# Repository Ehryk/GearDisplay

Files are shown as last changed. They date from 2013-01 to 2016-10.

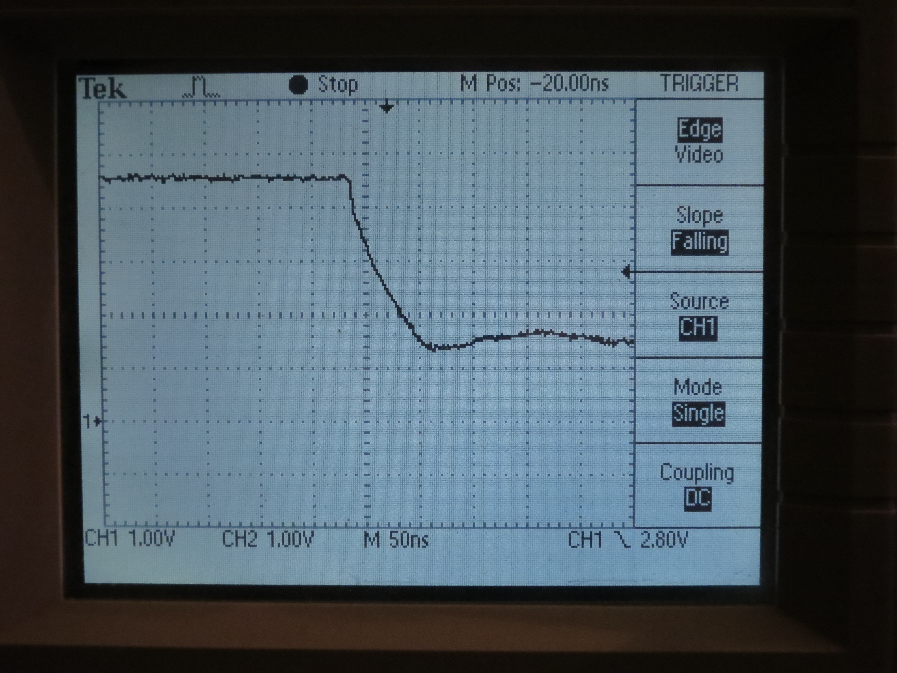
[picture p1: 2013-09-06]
Documentation/Pictures/2013.09.06 - Install/4 - Checking with Oscilloscope.jpg

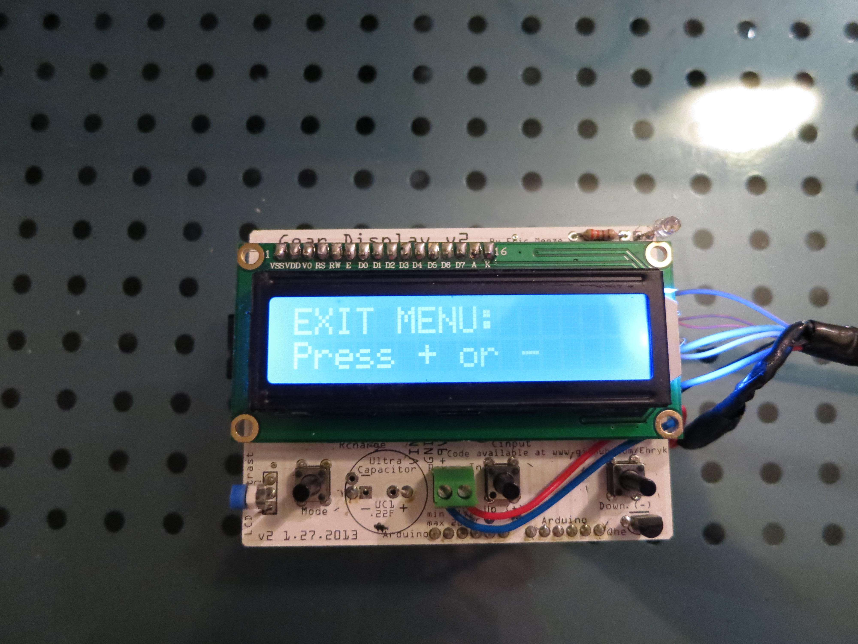
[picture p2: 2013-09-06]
Documentation/Pictures/2013.09.06 - Install/3 - Display On.jpg

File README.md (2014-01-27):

GearDisplay
===========

This is an Arduino based project that displays the currently selected gear in a manual transmission vehicle. It uses six Hall-Effect sensors connected to the analog inputs of the arduino, calculates the average, and then uses an adjustable tolerance value to see if any are outside of this tolerance value from the average. Ideally, if none are out of tolerance the transmission is in neutral, if only one is then it is the selected gear, and if more than one is then the tolerance is too low and it displays an Error. 

The key to this setup is one or more magnets on the shifter's metal shaft, and the six hall effect sensors at the approximate locations of the edge of the shaft when engaged in each gear (1-5 and Reverse). Six or more speeds are currently not supported, though less than five are (though the unused hall effect sensors should remain in the circuit providing roughly 2.5V).

**Videos**

 - Basic Operation Video: [Basic Operation Video](https://www.youtube.com/watch?v=FTQq74HFvWU)
 - Menu System in Detail: [Menu System Video](https://www.youtube.com/watch?v=9K3rxGJS8n4)
 - Sensor Voltages: [Sensor Voltages Video](https://www.youtube.com/watch?v=qHEV87LpvVI)

**Core**

This is a display-agnostic version of the core functionality. It will read the analog inputs, determine gear selection, and that's it. It will log detailed information to the Serial port if in debug mode and a device is listening for it. If you have your own display that isn't listed in the versions, start here.

**v1 - 16x2 LCD Display**

This is the first version I wrote, tuned for a standard 16x2 LCD screen. A schematic is included. This uses three push button switches and a potentiometer for the following functions: mode switching, tolerance up, tolerance down, and LCD contrast, respectively. This version has 12 display modes:

1. Basic Display
1. Basic Display - With Accent
1. Advanced Display
1. Advanced Display - With Accent
1. Variables Display (tolerance in voltage)
1. Variables Display (tolerance in internal units [0-1023])
1. Gear Voltages (Debug Only)
1. Gear Values (Debug Only)
1. Fill Mode - fills every position with the character of the gear (N for Neutral, 1 for first, etc.)
1. Enter Menu (press + or -)
1. Enter Log (press + or -)
1. Credits
1. Display off

v1

**v2 - 16x2 LCD Display - In Casing**

v1 was made to be mounted with the circuit board visible, but I then found some nice black project cases on eBay. This version is smaller to fit in the enclosure, uses an ultracapacitor keep-alive circuit to keep power to the unit briefly after the vehicle has been turned off for the final EEPROM writes, uses a transistor to selectively power the Hall Effect sensors (optional), and MC14490 hardware switch debouncer (optional). I installed it in a 2003 Jeep Wrangler Rubicon.

v2 Installed
v2 Sensor Ring

**v3 - Color Touchscreen**

Version 3 uses a color touchscreen for both display and user input, mode switching, and tolerance adjustments. Will come soon.

**Library**

This is where I will put a .cpp library of common features, when I get to it.

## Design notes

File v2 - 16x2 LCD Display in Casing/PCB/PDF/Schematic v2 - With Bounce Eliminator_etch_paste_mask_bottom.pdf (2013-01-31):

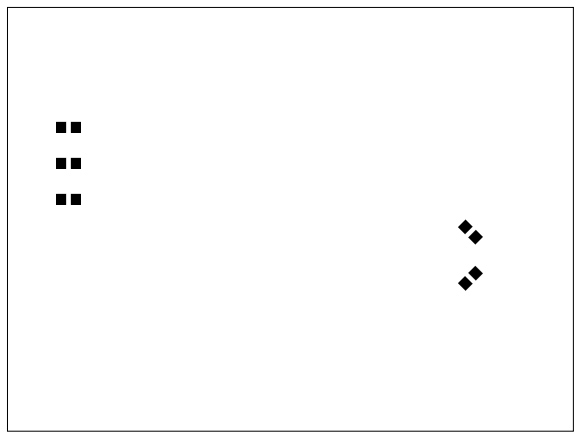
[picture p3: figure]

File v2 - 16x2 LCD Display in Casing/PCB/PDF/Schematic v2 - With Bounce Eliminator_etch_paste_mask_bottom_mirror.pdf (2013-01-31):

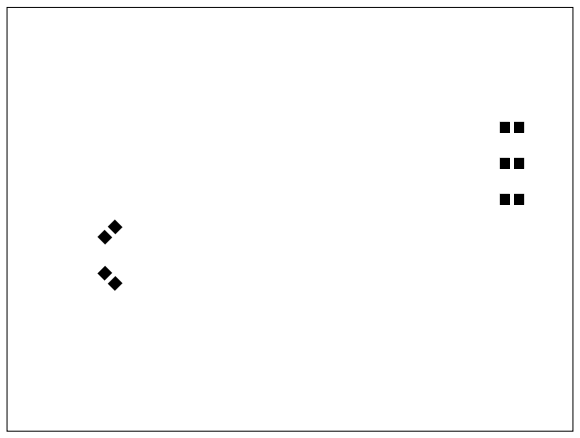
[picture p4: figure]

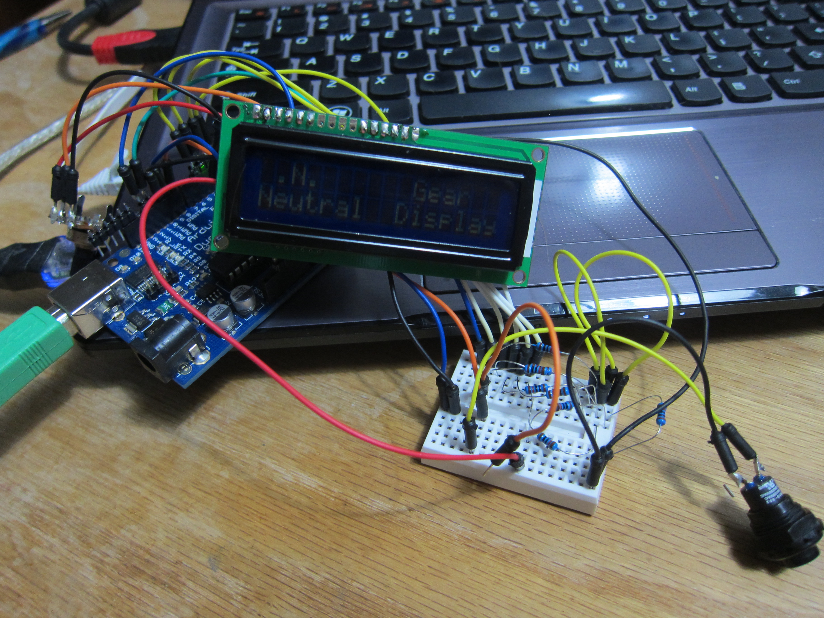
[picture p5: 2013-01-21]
Documentation/Pictures/2013.01.10 - Breadboard/4 - Neutral.jpg

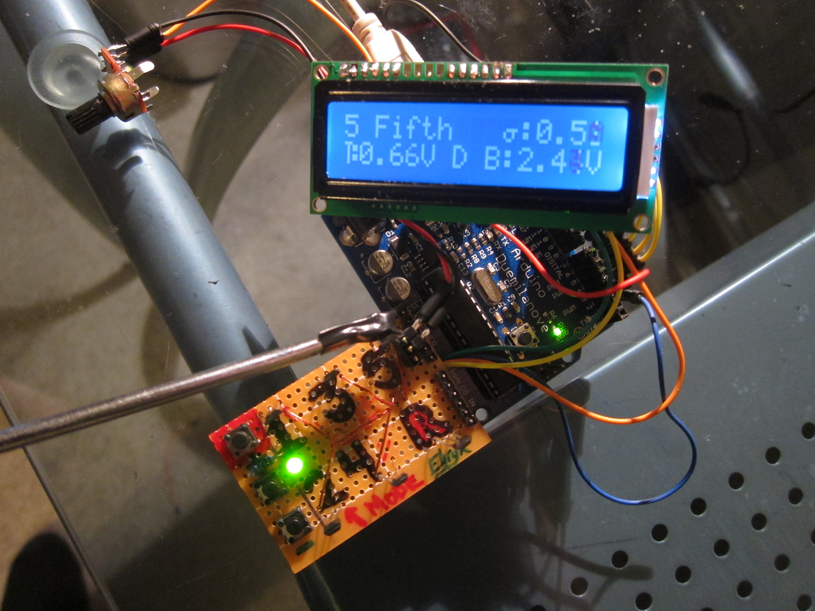
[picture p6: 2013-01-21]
Documentation/Pictures/2013.01.20 - Stripboard/2 - Advanced Display - In Gear.jpg

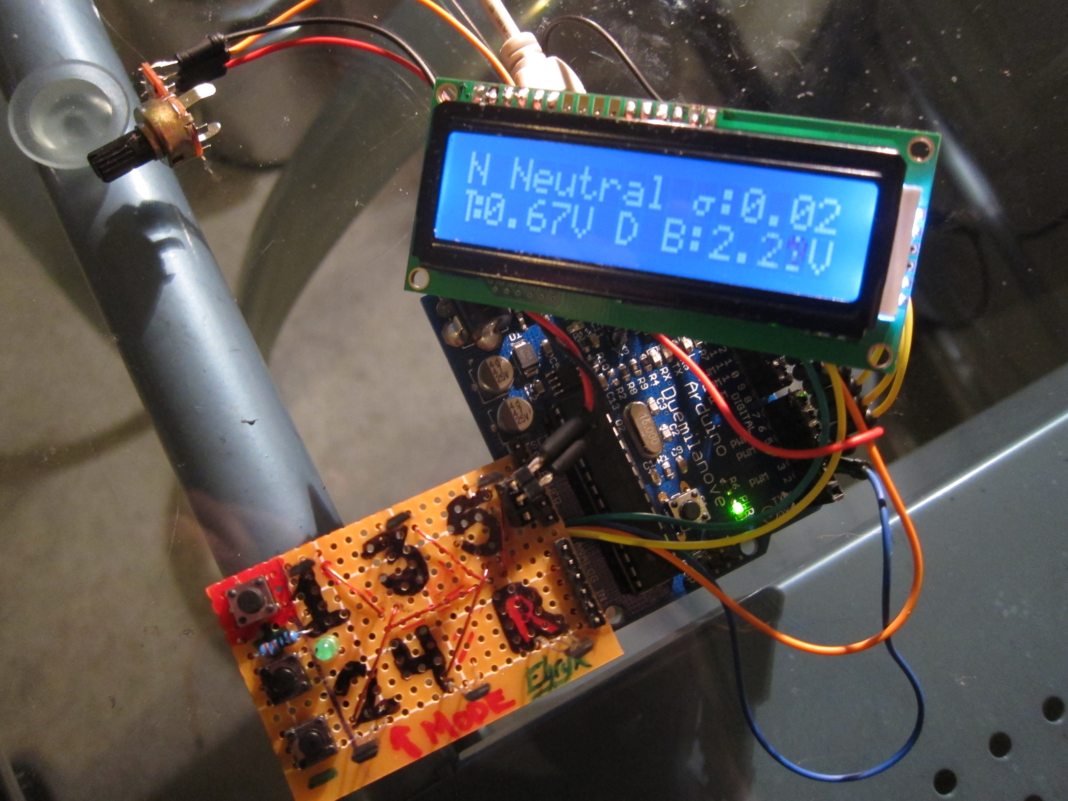
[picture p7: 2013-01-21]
Documentation/Pictures/2013.01.20 - Stripboard/3 - Advanced Display - Neutral.jpg

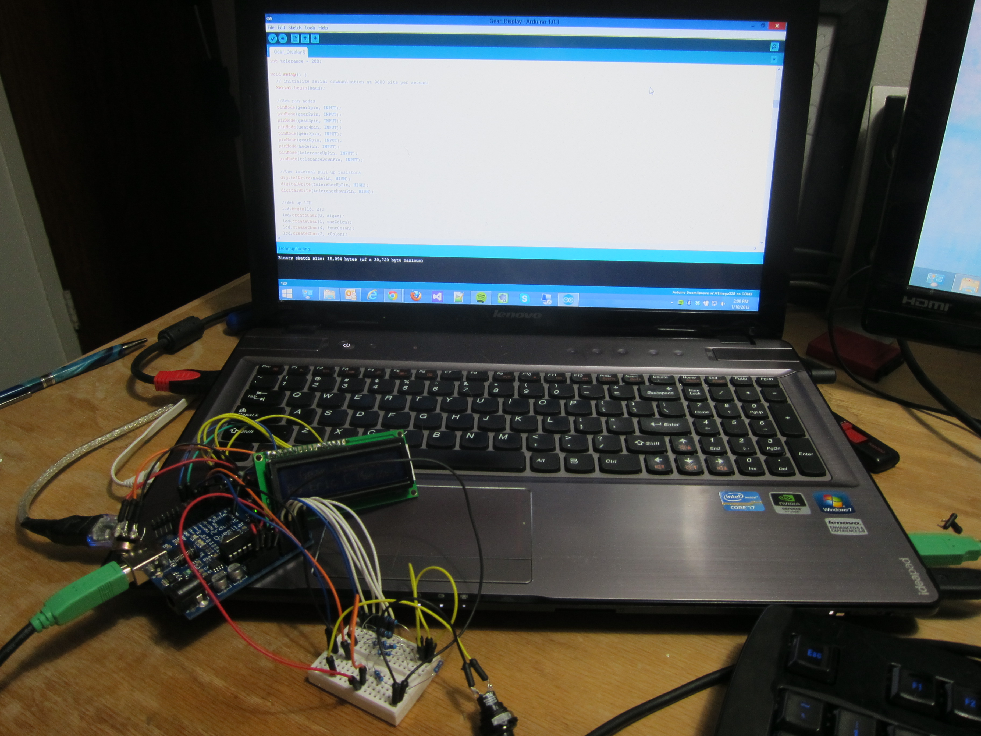
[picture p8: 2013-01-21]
Documentation/Pictures/2013.01.10 - Breadboard/1 - Coding it up.jpg

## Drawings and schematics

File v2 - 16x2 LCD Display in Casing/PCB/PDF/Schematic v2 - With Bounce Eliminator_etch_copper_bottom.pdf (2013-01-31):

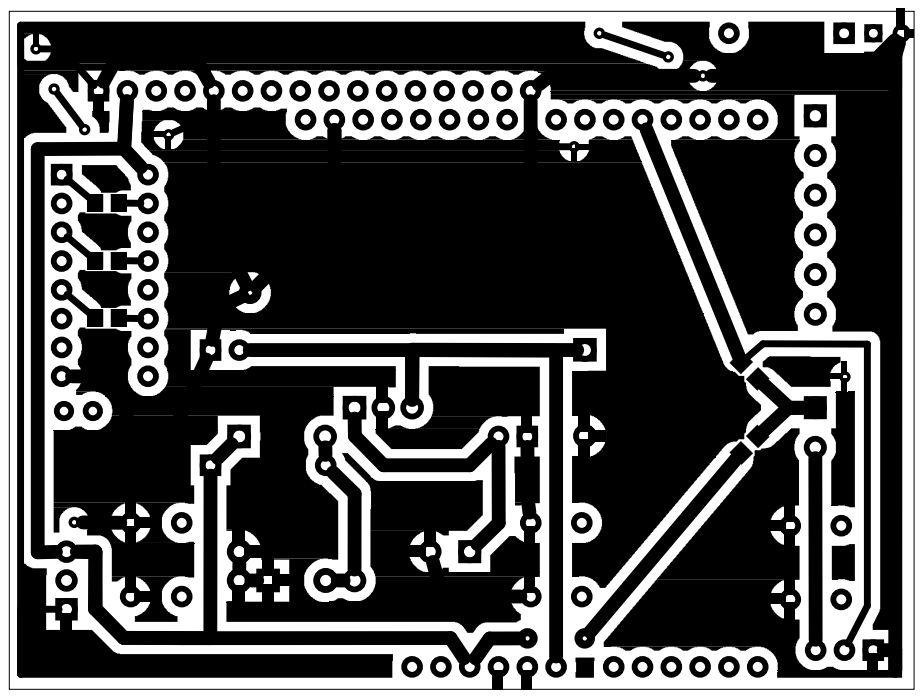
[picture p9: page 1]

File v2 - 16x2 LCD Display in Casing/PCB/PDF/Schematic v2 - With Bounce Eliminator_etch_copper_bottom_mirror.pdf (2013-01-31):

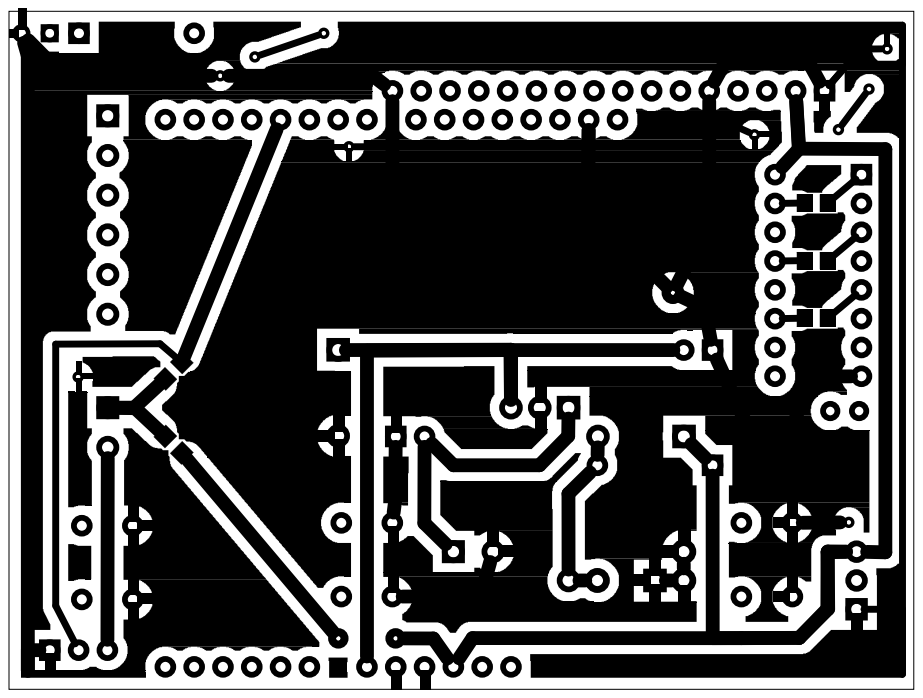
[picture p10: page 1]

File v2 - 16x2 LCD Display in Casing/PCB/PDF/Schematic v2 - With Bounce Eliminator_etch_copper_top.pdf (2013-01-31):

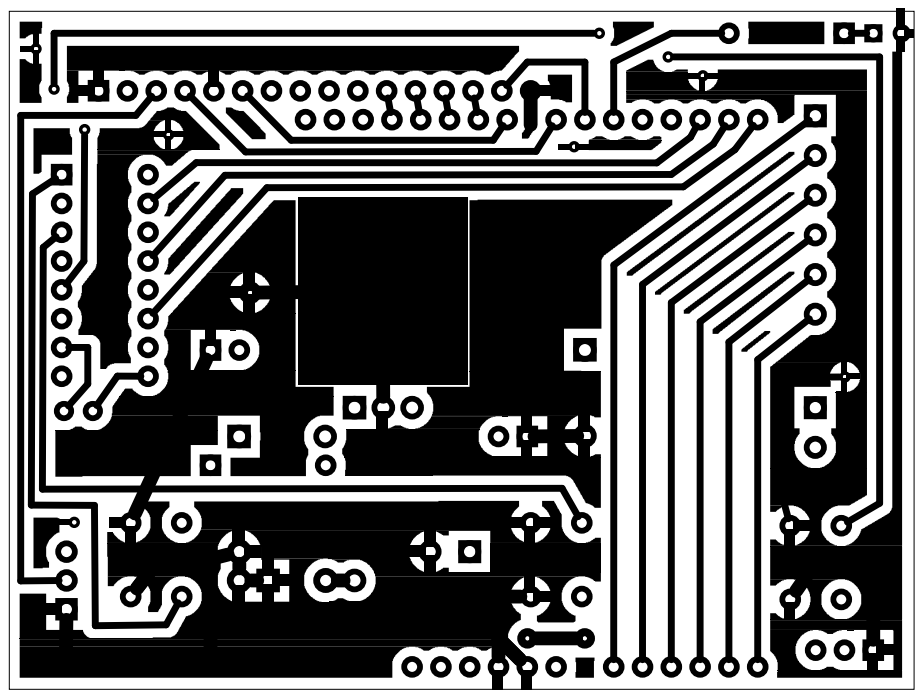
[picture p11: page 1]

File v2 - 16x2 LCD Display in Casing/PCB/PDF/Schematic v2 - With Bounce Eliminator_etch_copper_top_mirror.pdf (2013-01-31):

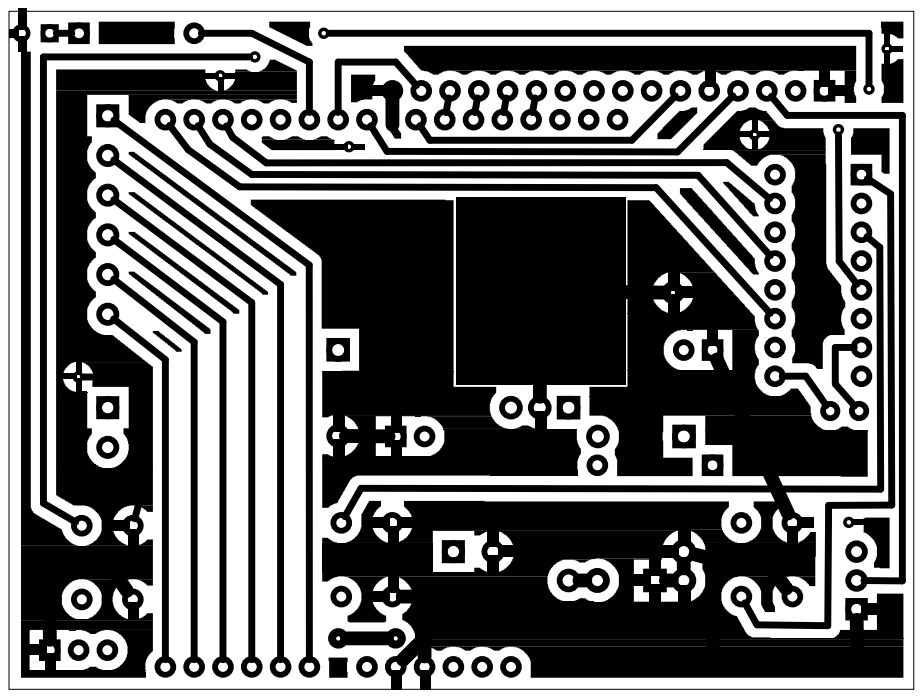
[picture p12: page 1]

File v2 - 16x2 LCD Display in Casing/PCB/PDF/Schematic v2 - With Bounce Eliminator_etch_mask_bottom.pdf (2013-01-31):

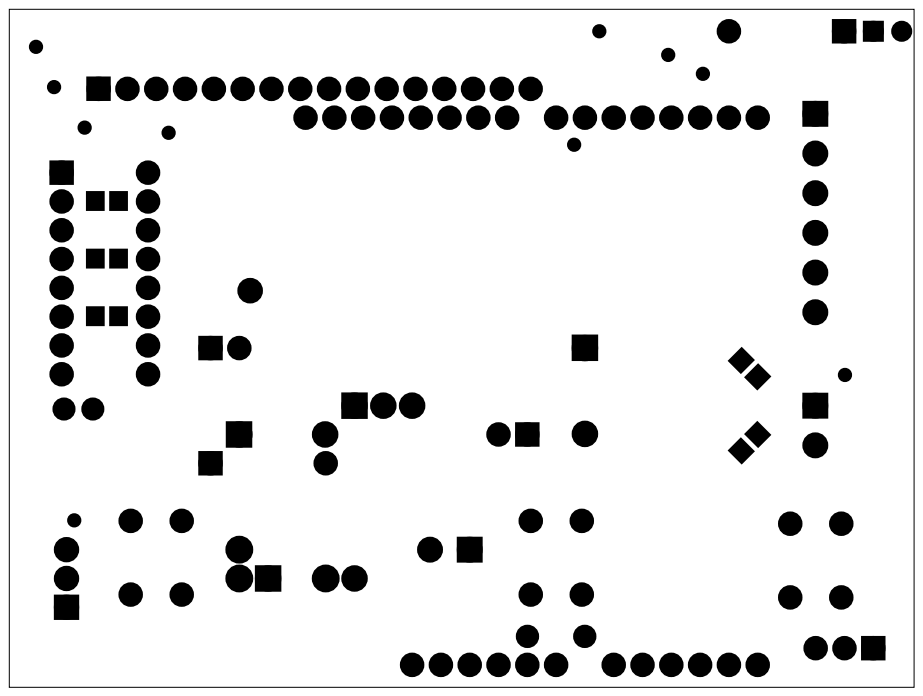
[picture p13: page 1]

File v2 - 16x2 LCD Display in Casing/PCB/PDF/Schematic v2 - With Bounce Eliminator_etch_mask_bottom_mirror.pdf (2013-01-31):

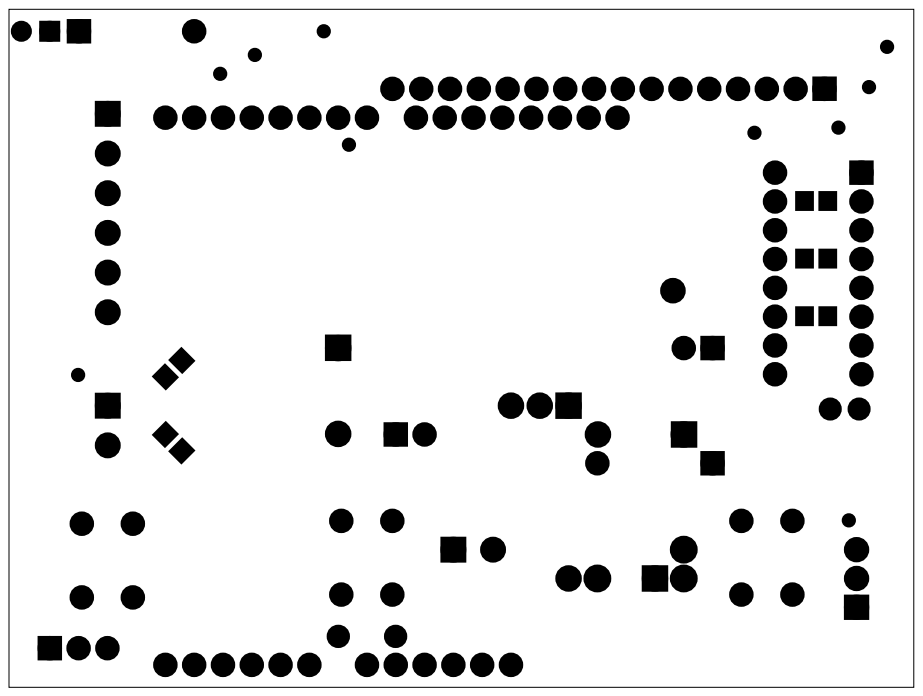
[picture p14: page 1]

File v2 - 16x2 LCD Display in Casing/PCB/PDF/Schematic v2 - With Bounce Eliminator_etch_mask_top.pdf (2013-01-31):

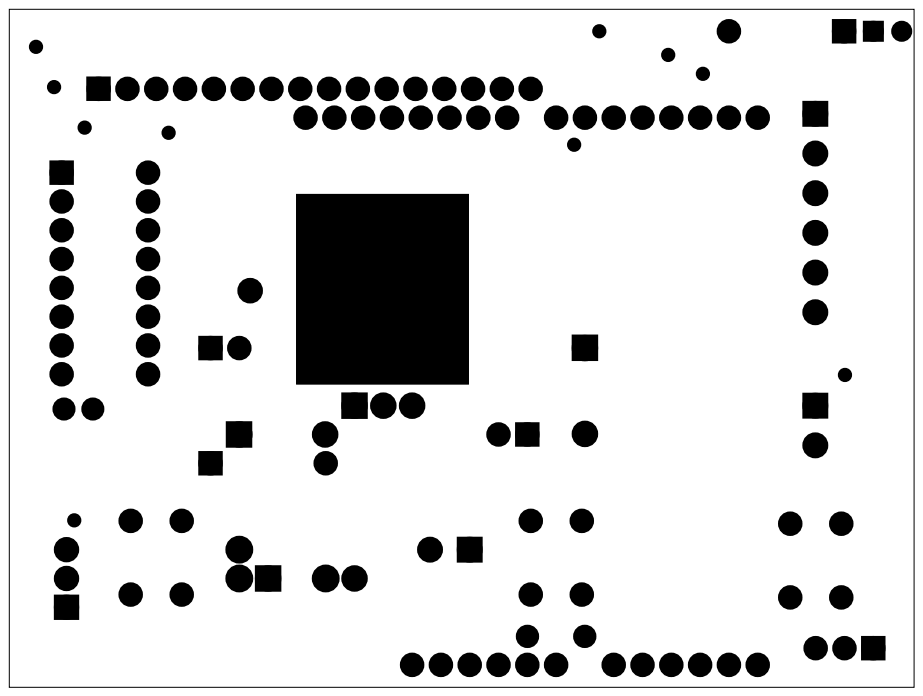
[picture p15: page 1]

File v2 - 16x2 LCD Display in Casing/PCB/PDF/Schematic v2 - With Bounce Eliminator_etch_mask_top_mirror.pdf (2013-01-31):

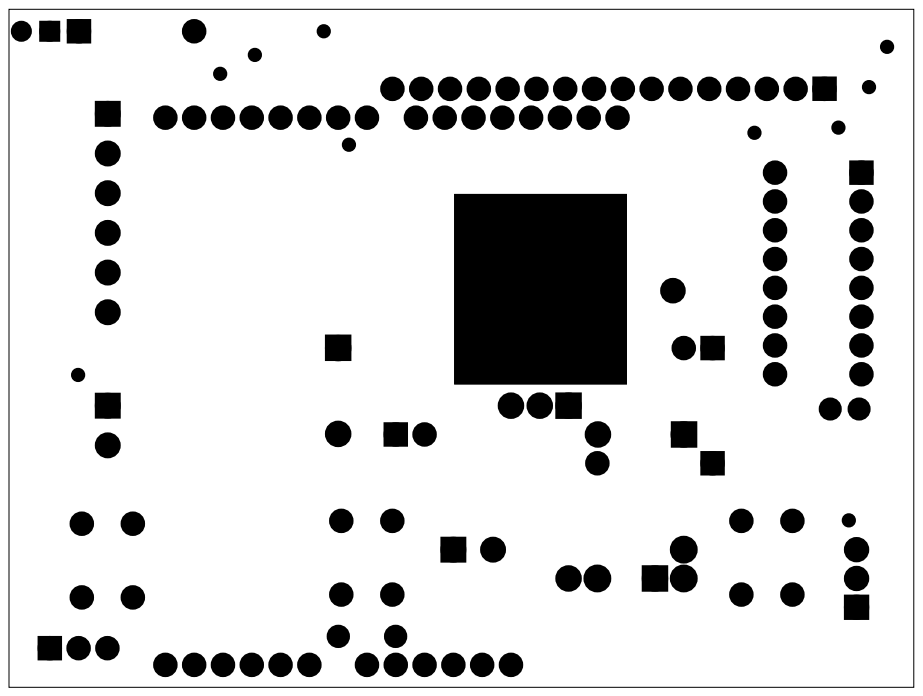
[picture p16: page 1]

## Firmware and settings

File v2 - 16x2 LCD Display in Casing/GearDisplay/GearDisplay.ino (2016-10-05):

/*
Manual Transmission Gear Display
v3.0 2016.10.04
Ehryk Menze
*/

#include <EEPROM.h>
#include <LiquidCrystal.h>

/* Number of Gears, including Reverse. Only tested on a 5 speed */
#define GEARS 6

/* Define Pin Usage */
//Digital Input Pins
#define MODE_PIN 2
#define UP_PIN 3
#define DOWN_PIN 4
#define ACC_PIN NA
#define SEN_PWR_PIN NA
#define LED_PIN 5
#define LCD_BRIGHTNESS_PIN 6
#define LCD_RS_PIN 7
#define LCD_ENABLE_PIN 8
#define LCD_D7 9
#define LCD_D6 10
#define LCD_D5 11
#define LCD_D4 12
#define INT_LED_PIN 13
int gearPin[GEARS] = {0, 1, 2, 3, 4, 5}; //Analog Input Pins

/* Compiler Constants, Defaults */
#define BAUD 57600 //Used for Serial communication
#define DEFAULT_TOLERANCE 100 //Initial Tolerance Value
#define DEFAULT_TOLERANCE_INCREMENT 5 //Initial Tolerance Increment/Decrement Value
#define DEFAULT_BRIGHTNESS 255 //Initial Brightness Value
#define BRIGHTNESS_INTERVAL 15 //LCD Brightness Increment to increase/decrease by (PWM, ranges from 0-255)
#define LOW_VOLTAGE_LIMIT 3900 //How low in mV on VCC Before ShutDown() (Save values to EEPROM). Set above 5000 to disable when not using a large capacitor to keep alive post-power cut (Needs about 200ms)
#define ACCENT_COUNT 5
const char accents[ACCENT_COUNT] = {'-', '*', '.', '~', '='};
#define DEBUG_INTERVAL 1000 //How often to output Debug information, in milliseconds
#define EEPROM_INTERVAL 5000 //How often to wait after last change to write to EEPROM
#define LOG_INTERVAL 60000 //How often to auto-save Log information to EEPROM, in milliseconds

//Set up LCD pins for 4 bit mode
//initialize the library with the numbers of the interface pins
LiquidCrystal lcd(LCD_RS_PIN, LCD_ENABLE_PIN, LCD_D4, LCD_D5, LCD_D6, LCD_D7);

//Declare Global Variables
//Values will range between 0 and 1023, (0V and 5V respectively)
//With a Resolution of 4.9mV / unit
int values[6];
int theoretical = 511; //This is what should be read by the ideal Hall Effect Sensor, in a neutral magnetic environment. (1023 / 2)
int numberActive = -2; //Number of gears engaged
int method = 0; //Method of determining gear engagement (Starting at MEAN_BASED)
int mode = 0; //Which display mode is selected
boolean saveMode = true; //Persists mode across power cycles
boolean inMenu = false; //Whether the user is in the menu system
int menuMode = 0; //Which menu mode is selected
boolean inLog = false; //Whether the user is in the log system
int logMode = 0; //Which log mode is selected
int screenMode = 0; //Which 'version' of a given screen is being displayed
int vcc = 5000; //Voltage input in mV, should be 5000mV (5V) in theory
int brightness = 255; //LCD Brightness
char accent = 0; //Surrounds gear char
int gear = -2; //Which gear is active, if any. 0 = Neutral.
int lastGear = -2; //Which gear was last active, if any. 0 = Neutral.
int baseline = 0; //The baseline from which any gear out of tolerance from is considered engaged
int tolerance; //How much a gear can vary from the baseline before considered engaged
int toleranceInterval = DEFAULT_TOLERANCE_INCREMENT; //How much to vary the tolerance on a single press
boolean inGear = false; //Whether or not the vehicle is in a gear
int led = 1; //Whether or not to light the LED when a gear is engaged (default), neutral, or off
boolean updateNeeded = 0; //Whether or not to update the display immediately
unsigned long displayLastUpdated = 0; //When the display was last updated
unsigned long updateInterval = 500; //When to update the display between non-immediate updates
boolean loopToggle = false;

unsigned long lastLoopStart = 0;

//Debugging
boolean debug = true;
unsigned long debugRefresh = 0;

//These are addresses in the EEPROM for persistent storage
boolean enableEEPROM = true; //Uses EEPROM
boolean clearEEPROM = false; // -- SET TO TRUE ONLY WHEN ADDRESSES CHANGE, or to reset EEPROM to defaults --
boolean eepromUpdateNeeded = false;
boolean powerLoss = false;
unsigned long eepromLastChanged = -1;
unsigned long eepromLastUpdated = 0;

//Logging
boolean enableLog = true;
boolean clearLogBoolean = false; // -- SET TO TRUE ONLY WHEN ADDRESSES CHANGE, or to reset persistent log  --
//Log Times in tenths of a second
unsigned long timeInGear[1 + 6]; //0 for Neutral, 1-R
unsigned long upTime = 0; //Time the unit has been on, persisting between power cycles
unsigned int shiftsToGear[6]; //Transitions from Neutral to a gear, 1-R
unsigned long lifeTimeInGear[1 + 6]; //Life Time persists across power cycles
unsigned long lifeUpTime = 0; //Life Time persists across power cycles
unsigned int lifeShiftsToGear[6]; //Life Shifts persists across power cycles
unsigned long logRefreshed = 0; //Time since log values last saved to EEPROM

/*=========*/
/*  SETUP  */
/*=========*/
//setup() gets called once at power on/reset of Arduino
void setup() {
  // initialize serial communication at 9600 bits per second:
  if (debug)
    Serial.begin(BAUD);
    
  analogReference(DEFAULT); //Use 5v Default AREF
  
  //Set Pin Directions
  for (int g = 0; g < GEARS; g++) {
    pinMode(g, INPUT);
  }
  pinMode(LED_PIN, OUTPUT);
  pinMode(INT_LED_PIN, OUTPUT);
  pinMode(MODE_PIN, INPUT);
  pinMode(UP_PIN, INPUT);
  pinMode(DOWN_PIN, INPUT);
  pinMode(LCD_BRIGHTNESS_PIN, OUTPUT);
  //pinMode(SEN_PWR_PIN, OUTPUT);
  //pinMode(ACC_PIN, OUTPUT);

  //Set Initial States
  //Use internal pull-up resistors
  digitalWrite(MODE_PIN, HIGH);
  digitalWrite(UP_PIN, HIGH);
  digitalWrite(DOWN_PIN, HIGH);
  //Internal LED Off
  digitalWrite(INT_LED_PIN, LOW);
  //Power up Sensors
  //digitalWrite(SEN_PWR_PIN, HIGH);
  
  //Set up LCD
  brightness = DEFAULT_BRIGHTNESS;
  setLCDBrightness(brightness);
  lcd.begin(16, 2);
  createCustomCharacters();
  
  tolerance = DEFAULT_TOLERANCE;
  
  //Initialize Log
  timeInGear[0] = 0;
  for (int g = 0; g < GEARS; g++) {
    timeInGear[g + 1] = 0;
    shiftsToGear[g] = 0;
  }
  
  //Read from EEPROM
  if (clearEEPROM) EEPROM.write(0, 0);
  if (enableEEPROM) readEEPROM();
  if (enableLog && !clearLog) readLog();
  
  writeCredits();
  delay(1500);
  lcd.clear();

  lastLoopStart = millis();
}

/*==========*/
/*   LOOP   */
/*==========*/
//loop() gets called repeatedly for the duration of power
void loop() {
  checkPowerLoss(); //Check for power loss
  if (powerLoss) shutDown();
  
  //Loop Timing
  unsigned long loopTime = millis() - lastLoopStart;
  if (millis() < lastLoopStart) loopTime = 0; //millis() overflow, ~70 days 
  lastLoopStart = millis();
  
  handleButtons();
  
  //Update the value variables
  readValues();
  baseline = computeBaseline(method);
  numberActive = countActive();
  int previous = gear;
  gear = activeGear();
  inGear = gear > 0;
  
  if (previous > 0) lastGear = previous; // If not Neutral
  updateNeeded = previous != gear;
  
  setLED(inGear);
  setLCDBrightness(brightness);
  
  //This saves all values to EEPROM, if a change has happened, and the requisite amount of time has passed since the last change
  if (enableEEPROM && eepromUpdateNeeded && eepromLastChanged >= 0 && millis() - eepromLastChanged > EEPROM_INTERVAL) writeEEPROM();
  
  if (enableLog) {
    if (previous == gear) { //Remained in a gear (or neutral)
      timeInGear[gear] += loopTime / 100; //Store in tenths
      lifeTimeInGear[gear] += loopTime / 100;
    }
    upTime += loopTime / 100; //Loop success, increment uptime
    lifeUpTime += loopTime / 100;
    if (previous == 0 && inGear) { //Shifted into a gear from Neutral
      shiftsToGear[gear - 1]++;
      lifeShiftsToGear[gear - 1]++;
    }
  }
  
  //This writes the Log values, if the log interval (in ms) has passed
  if (enableLog && millis() - logRefreshed > LOG_INTERVAL) writeLog();
  
  //This rereads in the case of an error or fault
  //(doesn't display errors, leaves last displayed values)
  if (!debug && gear < 0) return;
  
  if (debug && millis() - debugRefresh > DEBUG_INTERVAL) writeDebug(loopTime);
  
  //Update the display
  if (updateNeeded || millis() - displayLastUpdated > updateInterval)
    updateDisplay(mode, gear);

  loopToggle = !loopToggle;
  digitalWrite(INT_LED_PIN, loopToggle);
}

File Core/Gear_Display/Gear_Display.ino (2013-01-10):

/*
Manual Transmission Gear Display
Ehryk Menze
*/

#include <LiquidCrystal.h>
#include <stdlib.h>

//Configure Pins
int gear1pin = A0;
int gear2pin = A1;
int gear3pin = A2;
int gear4pin = A3;
int gear5pin = A4;
int gearRpin = A5;
int modePin = 8;
int toleranceUpPin = 9;
int toleranceDownPin = 10;

//Declare Value Variables
//Values will range between 0 and 1023, (0V and 5V respectively)
//With a Resolution of 4.9mV / unit
int gear1value = 0;
int gear2value = 0;
int gear3value = 0;
int gear4value = 0;
int gear5value = 0;
int gearRvalue = 0;
//This is what should be read by the ideal Hall Effect Sensor
//Probably useless in this application
int theoretical = 511;
int numberActive = -2;
int mode = 0;
boolean inGear = false;
unsigned long debugRefresh = 0;
//How often to refresh the serial port, in milliseconds
int refreshInterval = 1000;
int gear = -2;
int total = 0;
int average = 0;

//Parameters
boolean debug = true;
int baud = 9600;
int tolerance = 200;

void setup() {
  // initialize serial communication at 9600 bits per second:
  Serial.begin(baud);
  
  //Set pin modes
  pinMode(gear1pin, INPUT);
  pinMode(gear2pin, INPUT);
  pinMode(gear3pin, INPUT);
  pinMode(gear4pin, INPUT);
  pinMode(gear5pin, INPUT);
  pinMode(gearRpin, INPUT);
  pinMode(modePin, INPUT);
  pinMode(toleranceUpPin, INPUT);
  pinMode(toleranceDownPin, INPUT);
  
  //Use internal pull-up resistors
  digitalWrite(modePin, HIGH);
  digitalWrite(toleranceUpPin, HIGH);
  digitalWrite(toleranceDownPin, HIGH);
  
  writeCredits();
  delay(1500);
}

boolean checkPress(int pin) {
  return digitalRead(pin) == LOW && debounce(pin, LOW, 20, 6);
}

void loop() {
  // put your main code here, to run repeatedly:
  //Check for Mode Press
  if (checkPress(modePin)) {
    mode++;
    if (mode > 8) mode = 0;
    delay(100);
  }
  else if (checkPress(toleranceUpPin) && tolerance < 995) tolerance += 5;
  else if (checkPress(toleranceDownPin) && tolerance > 0) tolerance -= 5;
  
  //Update the value variables
  readValues();
  total = getTotal();
  average = getAverage(total);
  numberActive = countActive();
  gear = activeGear();
  inGear = gear > 0;
  
  //This rereads in the case of an error or fault
  //(doesn't display errors, leaves last displayed values)
  if (!debug && gear < 0) return;
  
  if (debug && millis() - debugRefresh > refreshInterval) {
    Serial.print("Mode: ");
    Serial.println(mode);
    
    Serial.print("Total: ");
    Serial.println(total);
    
    Serial.print("Average: ");
    Serial.print(average);
    Serial.print(" ");
    Serial.print(toVoltage(average));
    Serial.println("V");
    
    Serial.print("Tolerance: ");
    Serial.print(tolerance);
    Serial.print(" ");
    Serial.print(toVoltage(tolerance));
    Serial.println("V");
    
    Serial.print("In Gear: ** ");
    Serial.print(gearName(gear));
    Serial.print(" (");
    Serial.print(gearChar(gear));
    Serial.println(") **");
    
    if (inGear) {
      Serial.print(" - Active Gear: ");
      Serial.print(activeValue());
      Serial.print(" ");
      Serial.print(activeVoltage());
      Serial.println("V");
      Serial.print(" - Differential: ");
      Serial.println(abs(activeValue() - average));
    }
    else {
      Serial.println(" - Active Gear: N/A");
      Serial.println(" - Differential: N/A");
    }
    
    Serial.print("Gear 1: ");
    Serial.print(gear1value);
    Serial.print(" ");
    Serial.print(toVoltage(gear1value));
    Serial.println("V");
    
    Serial.print("Gear 2: ");
    Serial.print(gear2value);
    Serial.print(" ");
    Serial.print(toVoltage(gear2value));
    Serial.println("V");
    
    Serial.print("Gear 3: ");
    Serial.print(gear3value);
    Serial.print(" ");
    Serial.print(toVoltage(gear3value));
    Serial.println("V");
    
    Serial.print("Gear 4: ");
    Serial.print(gear4value);
    Serial.print(" ");
    Serial.print(toVoltage(gear4value));
    Serial.println("V");
    
    Serial.print("Gear 5: ");
    Serial.print(gear5value);
    Serial.print(" ");
    Serial.print(toVoltage(gear5value));
    Serial.println("V");
    
    Serial.print("Gear R: ");
    Serial.print(gearRvalue);
    Serial.print(" ");
    Serial.print(toVoltage(gearRvalue));
    Serial.println("V");
    
    Serial.print("Standard Deviation: ");
    Serial.println(getStandardDeviation(average));
    
    Serial.println();
    
    debugRefresh = millis();
  }
  
  //Update the display
  updateDisplay(mode, gear);
}

void readValues(){
  gear1value = readHallEffect(gear1pin);
  gear2value = readHallEffect(gear2pin);
  gear3value = readHallEffect(gear3pin);
  gear4value = readHallEffect(gear4pin);
  gear5value = readHallEffect(gear5pin);
  gearRvalue = readHallEffect(gearRpin);
}

int getTotal() {
  return gear1value + gear2value + gear3value + gear4value + gear5value + gearRvalue;
}

int getAverage(int total) {
  return total / 6;
}

float getStandardDeviation(int average) {
  float variance = 0;
  variance += pow(toVoltage(gear1value - average), 2);
  variance += pow(toVoltage(gear2value - average), 2);
  variance += pow(toVoltage(gear3value - average), 2);
  variance += pow(toVoltage(gear4value - average), 2);
  variance += pow(toVoltage(gear5value - average), 2);
  variance += pow(toVoltage(gearRvalue - average), 2);
  variance = variance / 6;
  return sqrt(variance);
}

float toVoltage(int value) {
  return value * 5.0 / 1023.0;
}

int readHallEffect(int pin) {
  return analogRead(pin);
}

int countActive() {
  //Return the number of pins avove tolerance
  int count = 0;
  
  if (active(gear1value)) count ++;
  if (active(gear2value)) count ++;
  if (active(gear3value)) count ++;
  if (active(gear4value)) count ++;
  if (active(gear5value)) count ++;
  if (active(gearRvalue)) count ++;
  
  return count;
}

int activePin() {
  //Return the pin above tolerance
  //Return -1 if more than one active
  
  if (numberActive == 0) return 0;
  if (numberActive >= 2) return -1;
  
  if (active(gear1value)) return gear1pin;
  if (active(gear2value)) return gear2pin;
  if (active(gear3value)) return gear3pin;
  if (active(gear4value)) return gear4pin;
  if (active(gear5value)) return gear5pin;
  if (active(gearRvalue)) return gearRpin;
  
  return -2;
}

int activeGear() {
  //Return the pin above tolerance
  //Return -1 if more than one active
  
  if (numberActive == 0) return 0;
  if (numberActive >= 2) return -1;
  
  if (active(gear1value)) return 1;
  if (active(gear2value)) return 2;
  if (active(gear3value)) return 3;
  if (active(gear4value)) return 4;
  if (active(gear5value)) return 5;
  if (active(gearRvalue)) return 6;
  
  return -2;
}
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

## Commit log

2013-01-10 Initial Commit. v1 - 16x2 LCD working on an Arduino 9 Selectable modes, adjustable tolerances. v1 Mostly complete.
    [Gear_Display.ino]
2013-01-10 Added v1 Fritzing schematic
    [Schematic.fzz]
2013-01-10 Wired tolerance switches in v2 schematic
    [Schematic.fzz]
2013-01-12 Massive update to v1 Schematic
    Routed PCB
    Added LED
    Added 7809 9V Stage 1 Regulator, Capacitors
    Added Silkscreen markings
    [Schematic.fzz]
2013-01-12 Added v1 BOM
2013-01-12 Updated BOM
2013-01-12 Added PCB Exports
    In both PDF and SVG
2013-01-12 Finishing Schematic Routing
    [Schematic.fzz]
2013-01-12 Added LED to schematic, exported in Gerber format
    [Schematic_contour.gm1, Schematic_copperBottom.gbl, Schematic_copperTop.gtl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]
2013-01-12 Updated Schematic
    Rearranged pin usage to improve layout
    LED now on a PWM pin
    LCD pins consolidated
    [Schematic.fzz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]
2013-01-12 Updated Code with new pin values
2013-01-12 Bug fixes in v1 Code
    [Gear_Display.ino]
2013-01-13 Minor v1 Schematic Update
    [Schematic.fzz]
2013-01-13 Added Arduino Reference.txt
    This is mean to house random arduino based information
    Like pinouts, electrical component information
2013-01-13 Massive v1 Menu Update, Logging Added
    Added a large scale logging system to track:
    Times in each gear, and neutral,
    Number of shifts,
    Uptime
    Persist these past power cycles, and
    Display these in a menu system.
    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
2013-01-13 Adding LCD Backlight wiring and code
    Wired LCD LED backlight to Schematic on PWM pin 3
    Moved LED to pin 2, non PWM
    Added brightness section of Menu submenu to update it
    [Schematic.fzz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]
2013-01-13 Broke LED out into a tab, localized custom LCD characters
    [Analysis.ino, Gear_Display.ino, LCD.ino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]
2013-01-13 Fixing comment typo - thanks Norm
    [Analysis.ino]
2013-01-15 Centering Schematics, minor updates
    [Schematic.fzz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]
2013-01-15 Added more LED modes
    City
    Highway
    Error
    [LED.ino, Menu_System.ino]
2013-01-18 Started v2 Schematic
    [Schematic.fzz]
2013-01-20 Using input voltage to compute true voltage, turning on backlight before opening credits, outputing POWER LOSS to LCD, minor fixes
    [Analysis.ino, Debug.ino, EEPROM.ino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]
2013-01-20 Minor fixes, display issue
    [Analysis.ino, Debug.ino, EEPROM.ino]
2013-01-20 Defining variables to pre-compiler constants to save RAM - Buttons and LED Pins
2013-01-20 Defining variables to pre-compiler constants to save RAM - Number of Gears
2013-01-21 Small menu fixes, debouce better
    [EEPROM.ino]
2013-01-21 Added new potential feature to the feature list - Bluetooth integration and RGB LED
2013-01-23 Tracking previous gear, displaying Vcc
2013-01-23 Delaying 2ms before reading HE sensors, no change :(
2013-01-28 Renamed v1 to v1.0, Slowing updateDisplay to every 500ms unless needed, removing SVG and Gerber PCB Exports
    [Schematic v1.0.fzz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]
2013-01-28 Started v1.1 - LCD in Casing
    Using a black casing with internal dimensions 80mm(W)x60mm(H)
    Added shutdown ultracapacitor circuit to save values before power down
    Reordered pins to accomodate close LCD/Arduino spacing
    [Schematic v1.1 - For Casing.fzz]
2013-01-28 Updated reference file (arduino tips)
2013-01-28 Correcting 7809 pinout, adding to ground fill
    [Schematic v1.1 - For Casing.fzz]
2013-01-29 v1.1 allowing for Arduino powered sensors, schematic updates
    [Schematic v1.1 - For Casing.fzz]
2013-01-29 Major Menu Update and Fixes
    Added Forward/Reverse log page
    Added Update Interval to Menu
    Fixed int overflow in log methods
    Using arrow, underscore for life displays in log
    Added Vlow customization page to Menu
    Minor other additions
    [EEPROM.ino, GearDisplay.ino, MenuSystem.ino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]
2013-01-29 Added NPN Transistor as switch for HE power, ground fill tweaks
    [Schematic v1.1 - For Casing.fzz]
2013-01-30 Calibrated Vcc to 1.1v bandgap against multimeter
2013-01-30 Minor v1.1 schematic tweaks
    [Schematic v1.1 - For Casing.fzz]
2013-01-30 Added Schematic and PCB export of Shift Sensor section
    [Schematic.fzz]
2013-01-31 Renamed v1.0 to v1, turning display backlight off when in display off mode
    [Schematic v1.fzz]
2013-01-31 Renamed v1.1 to v2, Adding MC14490 Switch Debouncer Schematic
    [Schematic v1.1 - For Casing.fzz, Schematic v2 - With Bounce Eliminator.fzz, Schematic v2.fzz]
2013-01-31 Renaming v2 to v3
    [Schematic v3.fzz, Schematic.fzz]
2013-01-31 Added Open Rectangle Shift Sensor Unit, Renamed 'Ring' to 'Rectangle'
    [Schematic v1 - Solid Rectangle.fzz, Schematic v2 - Open Rectangle.fzz]
2013-01-31 Added Zener clamping diode to v2 Schematic
    [Schematic v2 - With Bounce Eliminator.fzz]
2013-01-31 Replace v2 Schematic with the Bounce Eliminator one; jumpers have been added to allow operation without one
    [Schematic v2 - With Bounce Eliminator.fzz, Schematic v2.fzz]
2013-01-31 Updating v2 schematic labels, part details
    [Schematic v2.fzz]
2013-02-10 Updated Fine Tuning, LED2 Pin Mode
    [Schematic v1.fzz]
2013-02-10 Added Shift Sensor Unit v3
    [Schematic v3 - Two Piece.fzz]
2013-02-11 Updating v2 Schematic; ready for an order
    [Schematic v2.fzz]
2013-02-11 Updated Shift Sensor v3
    [Schematic v3 - Two Piece.fzz]
2013-03-09 Removed Silkscreen on v2 SSU where it overlapped the ground fill
    [Schematic v2 - Open Rectangle.fzz]
2013-03-09 Added labels to lower section of v3 SSU
    [Schematic v3 - Two Piece.fzz]
2013-09-06 Updating v2 pinout
    [Schematic v2.fzz]
2013-09-06 Fixing Menu LED Text
    [SubmenuMenu.ino]
2015-10-03 Added Shift Sensor Schematic v4 - Tighter Sensor Spacing
    [Schematic v4 - Two Piece (tight).fzz]
2015-10-03 Documentation: Added Install pictures and PCB Routing screenshot
2015-10-03 Voltage and Values pages in Menu are now uncorrected
2016-07-05 Adding Schematic v4 with closer sensors, 12V input removed
    [Schematic v4 - Two Piece (Closer).fzz]
2016-10-05 Shift Sensor Unit: Updating v4 (Closer)
    [Schematic v4 - Two Piece (Closer).fzz, Schematic v4 - Two Piece (tight).fzz, Schematic v4 - Two Piece Closer.fzz]
2016-10-05 GearDisplay: Updating pins used in code
2016-10-05 GearDisplay: Adding Schematic v3
    [Schematic v3.fzz]
2016-10-06 Schematic v3: Finishing routing
    [Schematic v3.fzz]
